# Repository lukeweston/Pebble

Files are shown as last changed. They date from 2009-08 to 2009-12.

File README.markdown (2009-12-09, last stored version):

General purpose Arduino sensor/LCD shield
-----------------------------------------

This is a moderately simple Arduino (Arduino Duemilanove or similar physical board form factor) shield for general
purpose I/O, including an alphanumeric 16 x 2 LCD display, two pushbutton inputs, a DS18B20 1-wire temperature
sensor, a light-dependant resistor, a potentiometer for analog input, and two reed relays to control external
circuits.

This Arduino shield could be used for many different applications, including simply as an education tool for
learning about controlling several different kinds of common I/O hardware devices with Arduino, with or without
the Aiko software framework.

As another example of a potentially very interesting application, a shield like this could be combined with an
Arduino and an XBee RF communication module, and/or an Arduino ethernet shield, to create a distributed mesh
network of control nodes for a automation system, where, for example, the system can be controlled via input menus
on the LCD display at each node, the temperature at each node can be read off, and the light level at each node
can be read off.

With two reed relays on the board, there is plenty of scope for hacking interfaces to control your lighting,
heating or hot water service, to name just a few possible examples, for a home automation kind of application.

Arduino digital interface pins 8-13 are not connected; and can be used by the Arduino ethernet shield (which uses
the SPI interface) "in parallel" with this shield.

Arduino pin assignments:
------------------------
		
		Digital pins:
		UART RXD from XBee module:		0
		UART TXD to XBee module:		1
		LCD shift register strobe:		2
		LCD shift register data:		3
		LCD shift register clock:		4
		DS18B20 sensor 1-Wire data bus:		5
		Reed relay output 1:			6
		Reed relay output 2:			7
		
		Analog pins:
		LDR analog input:			A0
		Pot analog input:			A1
		Multiplexed (analog) pushbutton input:	A2

-------------------------------------------------------------------------------------------------------
The following is a bill-of-materials for the 'Pebble', all sourced from Digi-Key. Prices in USD.
Does NOT INCLUDE LCD.

Item					Digikey no.	Unit price				Subtotal	
--------------------------------------------------------------------------------------------------------
5 x 10 k resistors			10KQBK-ND		0.064 (minimum quantity 5)	0.320
2 x 100 R resistors			100QBK-ND		0.064 (minimum quantity 5)	0.128
2 x 100 k resistors			100KQBK-ND		0.064 (minimum quantity 5)	0.128
1 x 39 k resistor			39KQBK-ND		0.064 (minimum quantity 5)	0.064
1 x 22 k resistor			22KQBK-ND		0.064 (minimum quantity 5)	0.064
1 x 4.7 k resistor			4.7KQBK-ND		0.064 (minimum quantity 5)	0.064

1 x 10 k trimpot			D4AA14-ND		0.36				0.36
1 x 10 k pot				3310C-001-103L-ND	2.56				2.56

2 x 100 nF capacitor			399-4151-ND		0.16				0.32
1 x 10 uF electrolytic			493-1144-ND		0.24				0.24

1 x LDR					PDV-P8001-ND		2.14				2.14
1 x DS18B20				DS18B20+PAR-ND		5.04				5.04
1 x LD1117V33				497-1491-5-ND		0.78				0.78
1 x 4094				497-1373-5-ND		0.53				0.53

2 x 1N5819				1N5819FSCT-ND		0.37				0.74
1 x 3 mm red LED			160-1708-ND		0.09				0.09
1 x 3 mm green LED			160-1710-ND		0.09				0.09	

4 x tactile pushbutton switches		CKN9074-ND		0.13				0.52
2 x 14-pin IC socket (optional)		3M5462-ND		0.18				0.36
1 x 16-pin IC socket			3M5463-ND		0.18				0.18
2 x 10-pin 2 mm female headers		S5751-10-ND		1.05				2.10
2 x 16-pin 0.1" female headers		S7049-ND		0.92				1.84
2 x 30-pin breakaway header pin strip	S1212E-30-ND		1.45				2.90
1 x 6-pin 0.1" right-angle header	S5481-ND		0.74				0.74
2 x 5 v reed relays			HE100-ND		1.50				3.00
-------------------------------------------------------------------------------------------------------
									Total Price (per unit) 25.30

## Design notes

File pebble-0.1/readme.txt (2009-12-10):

This was the initial, first-generation prototype of the device.
Eagle files are included in pebble-0.1.sch and pebble-0.1.brd, and pebble-0.1-test.pde contains some
simple Arduino code (which is *not* nice Aiko-framework code) to test most of the hardware components.

Only one of these was ever built, and you probably don't want to build one, so detailed documentation,
CAM files, images, and further resources are probably unneccessary.

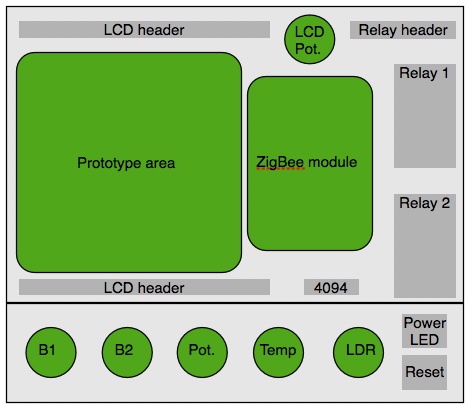
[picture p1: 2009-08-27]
pebble-0.5/ArduinoSensorLCDShield_Design.jpg

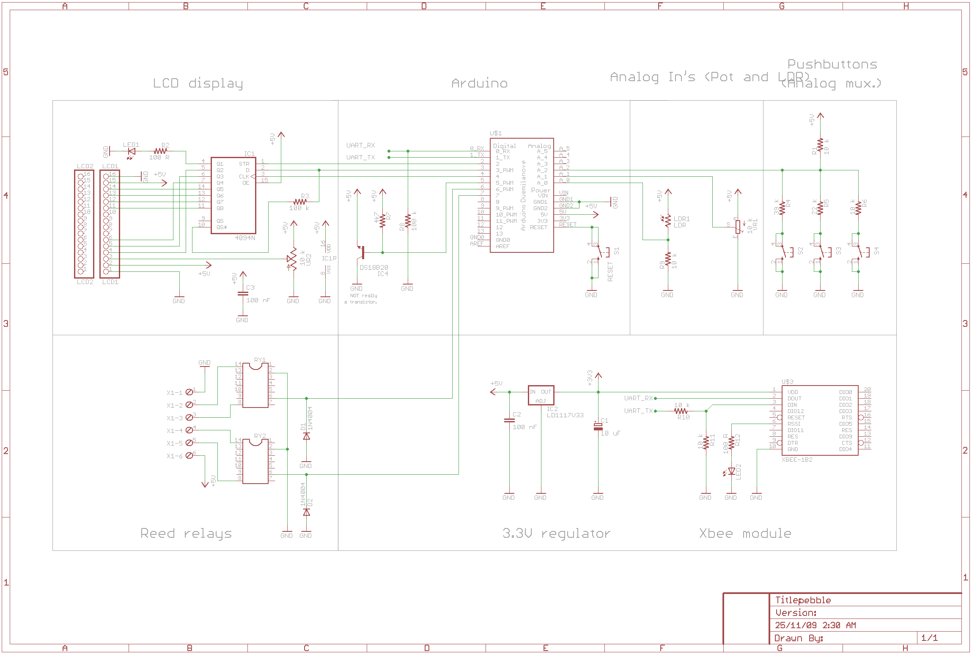
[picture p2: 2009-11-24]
pebble-1.0/pebble-sch.png

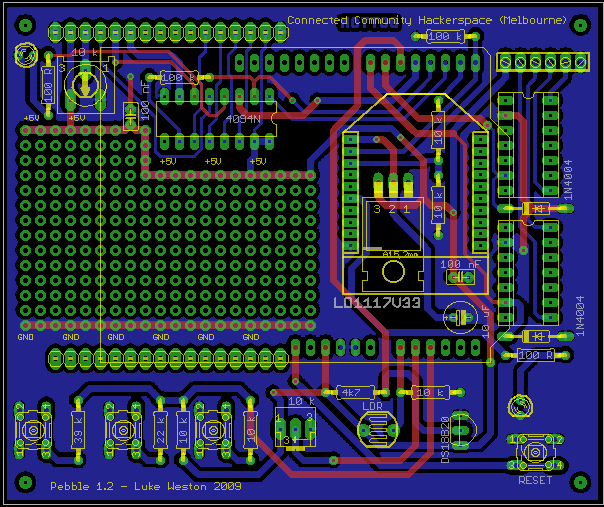
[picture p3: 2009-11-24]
pebble-1.0/pebble-pcb.png

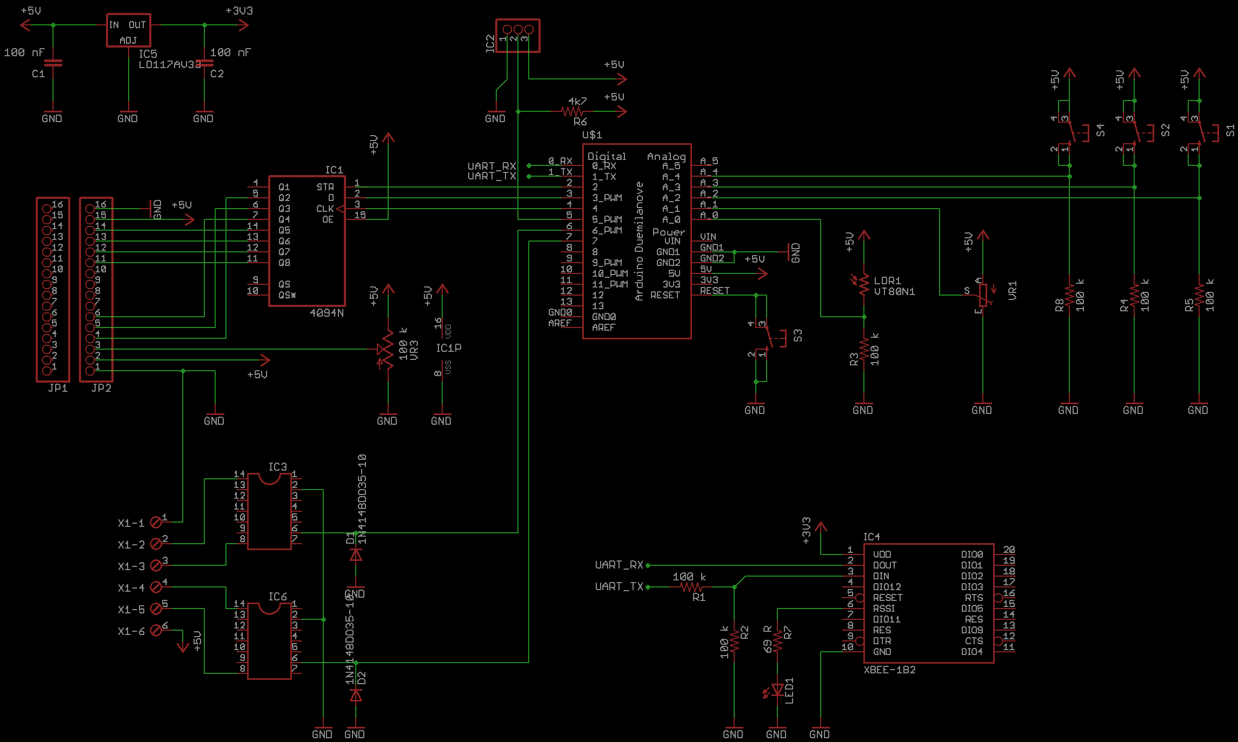
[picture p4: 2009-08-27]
pebble-0.5/pebble-sch.png

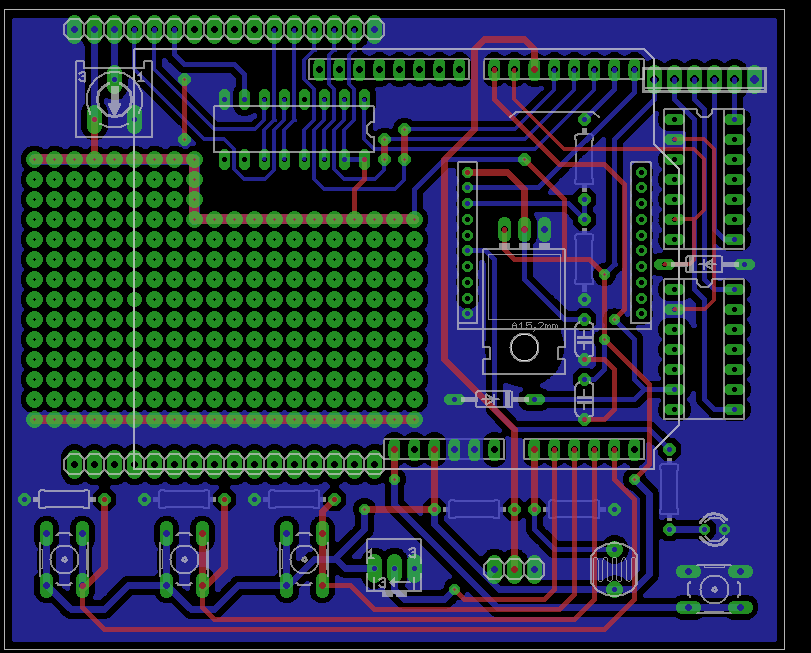
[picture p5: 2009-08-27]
pebble-0.5/pebble-pcb.png

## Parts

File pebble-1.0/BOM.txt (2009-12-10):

The following is a bill-of-materials for 'Pebble', all sourced from Digi-Key.
All prices in USD. Prices are (except for the resistors) for single quantities, without any volume pricing breaks.
Does NOT INCLUDE LCD.

			Item					Digikey no.	Unit price				Subtotal	
-------------------------------------------------------------------------------------------------------------------------------------
R1, R6, R9, R10, R11	5 x 10 k resistors			10KQBK-ND		0.064 (minimum quantity 5)	0.320
R2, R12			2 x 100 R resistors			100QBK-ND		0.064 (minimum quantity 5)	0.128
R3, R8			2 x 100 k resistors			100KQBK-ND		0.064 (minimum quantity 5)	0.128
R4			1 x 39 k resistor			39KQBK-ND		0.064 (minimum quantity 5)	0.064
R5			1 x 22 k resistor			22KQBK-ND		0.064 (minimum quantity 5)	0.064
R7			1 x 4.7 k resistor			4.7KQBK-ND		0.064 (minimum quantity 5)	0.064

VR1			1 x 10 k pot				3310C-001-103L-ND	2.56				2.56
VR2			1 x 10 k trimpot			D4AA14-ND		0.36				0.36

C1			1 x 10 uF electrolytic			493-1144-ND		0.24				0.24
C2, C3			2 x 100 nF capacitor			399-4151-ND		0.16				0.32

LDR1			1 x LDR					PDV-P8001-ND		2.14				2.14
IC4			1 x DS18B20				DS18B20+PAR-ND		5.04				5.04
IC2			1 x LD1117V33				497-1491-5-ND		0.78				0.78
IC4			1 x 4094				497-1373-5-ND		0.53				0.53

D1, D2			2 x 1N5819				1N5819FSCT-ND		0.37				0.74
LED1			1 x 3 mm green LED			160-1710-ND		0.09				0.09	
LED2			1 x 3 mm red LED			160-1708-ND		0.09				0.09

X1			1 x 6-pin 0.1" right-angle header	S5481-ND		0.74				0.74
S1-S4			4 x tactile pushbutton switches		CKN9074-ND		0.13				0.52
RY1, RY2		2 x 5 v reed relays			HE100-ND		1.50				3.00
LCD1, LCD2 headers 	2 x 16-pin 0.1" female headers		S7049-ND		0.92				1.84

Socket for IC4		1 x 16-pin IC socket			3M5463-ND		0.18				0.18
Socket for XBee		2 x 10-pin 2 mm female headers		S5751-10-ND		1.05				2.10
Mounting headers	2 x 30-pin breakaway header pin strip	S1212E-30-ND		1.45				2.90
Sockets for relays	2 x 14-pin IC socket (optional)		3M5462-ND		0.18				0.36

------------------------------------------------------------------------------------------------------------------------------------
												Total Price (per unit) 25.30
# U3: XBee digital radio module
# U1: Arduino (Duemilanove or similar)
# HD44780 LCD display with appropriate form factor

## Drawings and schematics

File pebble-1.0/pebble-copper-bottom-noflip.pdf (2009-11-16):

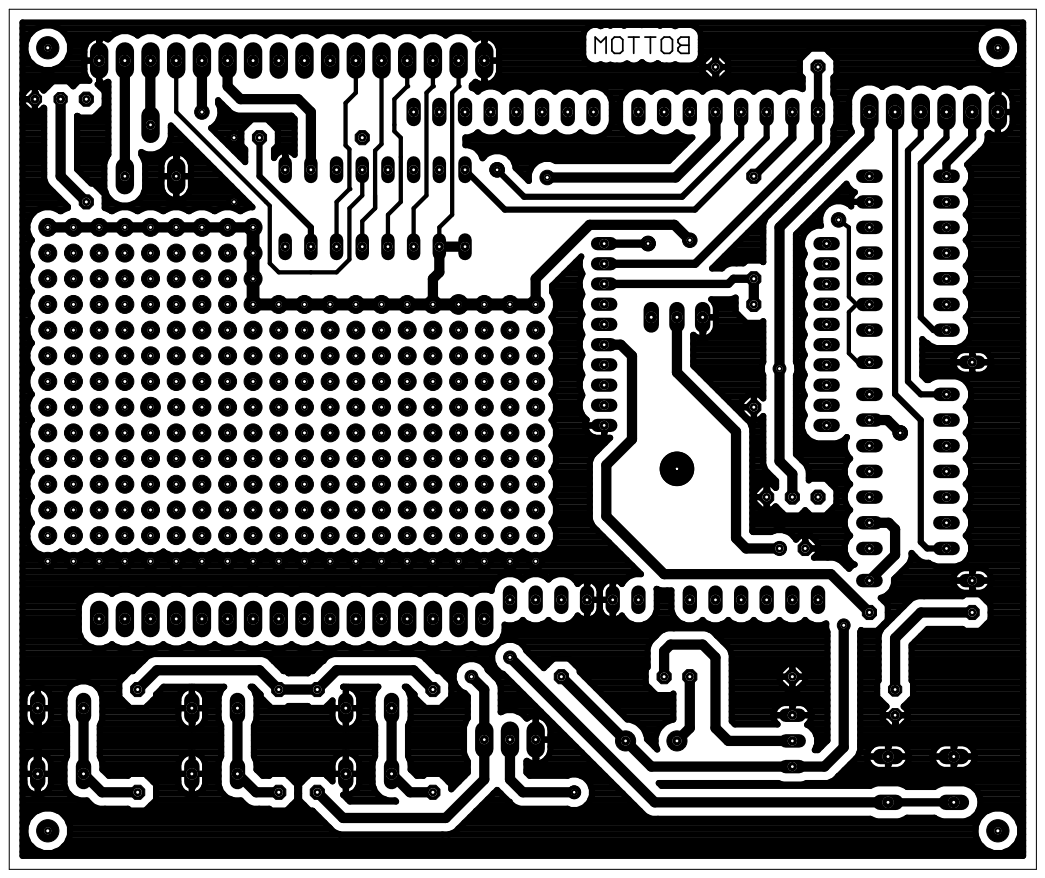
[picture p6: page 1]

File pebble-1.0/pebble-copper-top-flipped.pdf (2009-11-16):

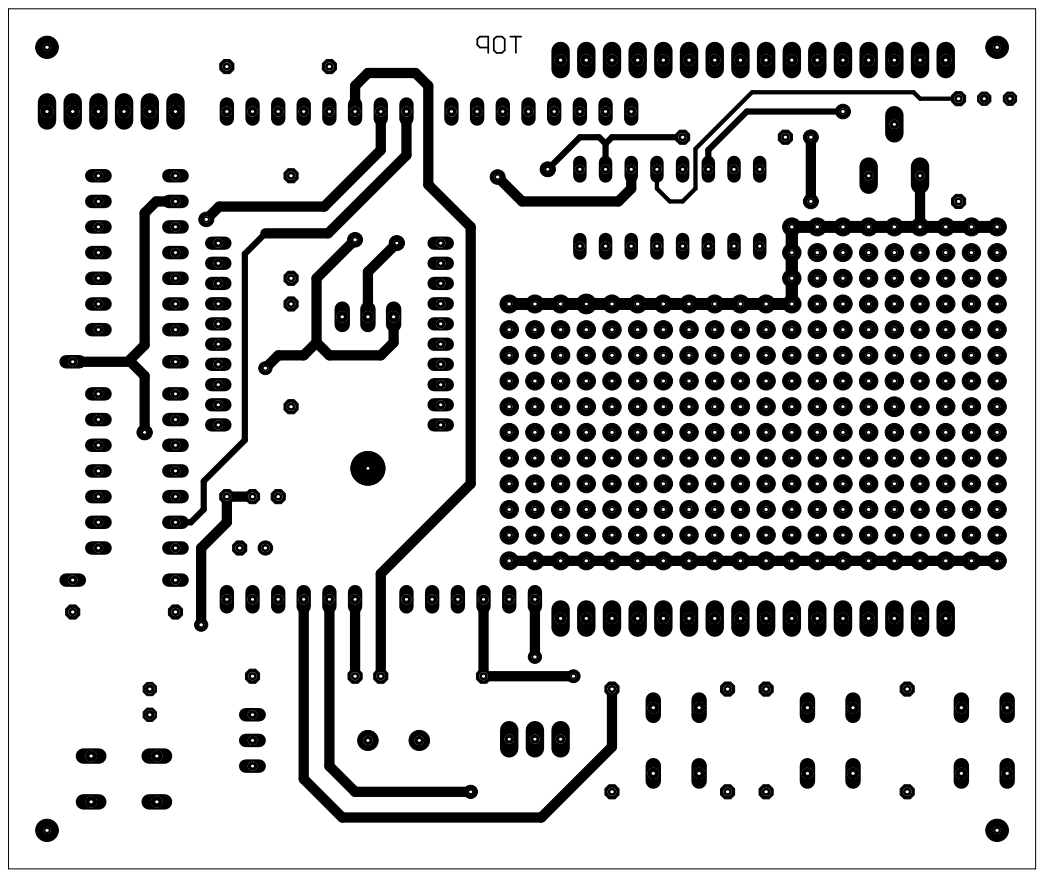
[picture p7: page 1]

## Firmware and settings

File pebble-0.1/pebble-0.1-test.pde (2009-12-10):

/* Simple code for hardware test on first-generation Pebble shield
Luke Weston, 2009
*/

#include <LCD3Wire.h> 
#include <DallasTemperature.h>
#include <stdio.h>

#define LCD_LINES 2
#define DOUT_PIN 3
#define STR_PIN 2
#define CLK_PIN 4
#define ONEWIRE 5
#define RELAY_A 6
#define RELAY_B 7

#define LDR 0
#define POT 1
#define RIGHT_BUTTON 2
#define LEFT_BUTTON 3

  LCD3Wire lcd = LCD3Wire(LCD_LINES, DOUT_PIN, STR_PIN, CLK_PIN);
  DallasTemperature tempSensor;
  
  char buf[8]="0";
      
void setup()
  { 
    lcd.init();
    tempSensor.begin(ONEWIRE);
    pinMode(RELAY_A, OUTPUT);
    pinMode(RELAY_B, OUTPUT);
  }

void loop()
  {  
    //lcd.clear();
    lcd.cursorTo(1,0);
    lcd.printIn(itoa(analogRead(POT), buf, 10));
      
    sprintf(buf, "%.2f", (tempSensor.getTemperature()));
    lcd.cursorTo(1,6);
    lcd.printIn(buf);
    
    lcd.cursorTo(1,12);
    lcd.printIn(itoa(analogRead(LDR), buf, 10));
    lcd.cursorTo(2,0);
    lcd.printIn(itoa((analogRead(LEFT_BUTTON) / 1023), buf, 10));
    lcd.cursorTo(2,12);
    lcd.printIn(itoa((analogRead(RIGHT_BUTTON) / 1023), buf, 10));
    
    digitalWrite(RELAY_A, HIGH);
    digitalWrite(RELAY_B, LOW);
    delay(50);
    
    digitalWrite(RELAY_A, LOW);
    digitalWrite(RELAY_B, HIGH);  
}

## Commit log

2009-06-23 Files for general-purpose Arduino I/O shield
    [shield 2.brd, shield 2.sch, shield 3.brd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]
2009-06-23 Made some minor revisions, and added to the doc
    [shield 2.brd, shield 2.sch, shield 3.brd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]
2009-07-05 added finished product XBee shield
    [shield-final.brd, shield-final.sch]
2009-07-07 made some minor fixes to the board
    [shield-final.brd, shield-final.sch]
2009-07-07 Added shield test Arduino file
2009-07-09 Revised the board design, wrote docs
    [sensor-LCD-shield.brd, sensor-LCD-shield.sch]
2009-07-09 cleaned up a bit
    [shield 2.brd, shield 2.sch, shield 3.brd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]
2009-07-09 organised files a bit
    [shield 3.brd, shield 3.sch, shield-final.brd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]
2009-07-09 tidied up a bit
    [shield-final.brd, shield-final.sch]
2009-07-09 renamed repository
    [sensor-LCD-shield.brd, sensor-LCD-shield.sch]
2009-08-19 Moved prototype into it's own sub-directory.
    [sensor-LCD-shield.brd, sensor-LCD-shield.sch]
2009-08-19 Added Luke's new 1.0 draft design.
    [pebble.brd, pebble.sch]
2009-08-27 added image file
    [pebble.brd, pebble.sch, sensor-LCD-shield.brd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]
2009-08-29 Some minor hardware revisions
    [pebble.brd, pebble.sch]
2009-10-21 added ring buffer LED hack
    [pebble.brd, pebble.sch]
2009-10-22 Updated BOM and some other tweaks
    [pebble.brd, pebble.sch]
2009-10-29 minor board layout tweak
    [pebble.brd, pebble.sch]
2009-10-30 tweaks for manufacturing reliability
    [pebble.brd]
2009-11-10 Tweaked board tracks slightly
    [pebble.brd]
2009-11-11 minor finshing tweaks
    [pebble.brd, pebble.sch]
2009-11-12 very minor tweaks
    [pebble.brd]
2009-11-16 minor tweaks to improve manufacturability
    [pebble.brd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]
2009-11-23 tweaked Gerber files
    [pebble.brd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]
2009-11-24 tweaked silkscreen, holes and regenerated Gerbers
    [pebble.brd, pebble.sch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]
2009-11-24 tweaked Gerbers
    [pebble.brd, pebble.sch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]
2009-12-09 Updated BOM
2009-12-10 cleaning up repository
    [pebble-0.1.brd, pebble-0.1.sch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]
2010-02-17 Replaced all axial parts with equivalents from Sparkfun lib with 1mm holes
    [pebble.brd, pebble.sch]
2010-02-17 * Start of major reorganisation around input section to allow cleaner routing and more logical association of input sub-systems with inputs
    [pebble.brd]
